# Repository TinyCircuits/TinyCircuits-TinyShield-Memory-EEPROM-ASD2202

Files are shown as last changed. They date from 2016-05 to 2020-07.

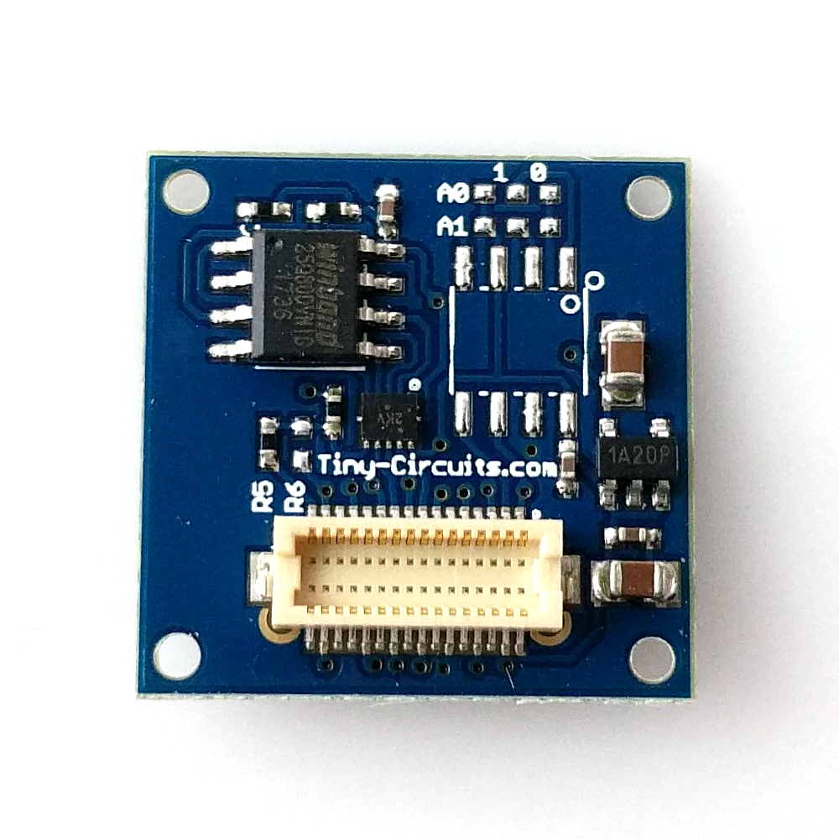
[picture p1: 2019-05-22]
images/Flash Memory/ASD2202-R-F-Tutorial-Image-01.jpg

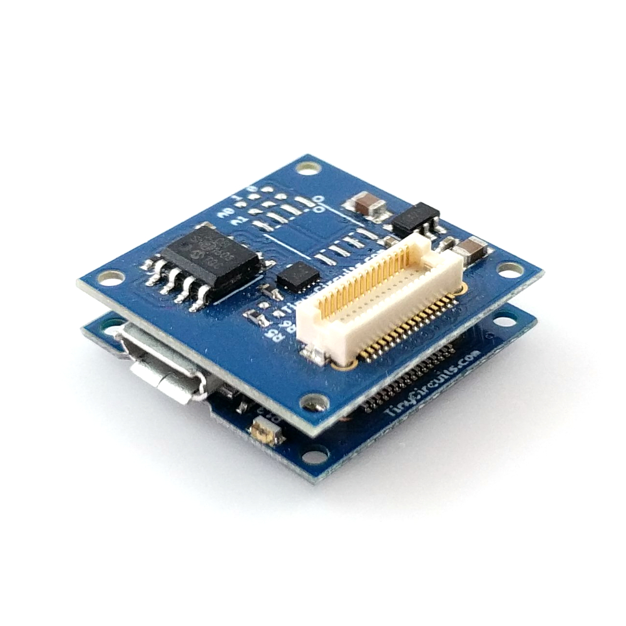
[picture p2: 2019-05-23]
images/SRAM/ASD2202-R-S-Tutorial-Image-03.jpg

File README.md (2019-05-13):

# TinyCircuits TinyShield EEPROM / Flash / SRAM Memory Board
## ASD2202 Rev3

The design files are located under design_files/ for the TinyCircuits ASD2202 Rev 3 PCB.  This is a TinyShield board (20mm x 20mm) that has options for several different memory ICs.

Format is in Cadsoft Eagle format - Eagle version 6.2 was used for the original design.

For more infomation on this, check out the product page at TinyCircuits.com:  https://tinycircuits.com/products/eeprom-tinyshield

# License:

Design by TinyCircuits.
All design files are released under the Creative Commons Attribution Share-Alike 3.0 License, see the following link for details: http://creativecommons.org/licenses/by-sa/3.0

All text above must be included in any redistribution or derived design

This project uses designs and concepts developed as part of the Arduino project and the LilyPad project.  The TinyCircuits design files themselves (schematics, PCB and libraries) are not directly derived from these works' design files and have been created new, however the concepts and basic architecture behind the TinyDuino and TinyLily products are derived and we thank the hard work of the organizations below for their contributions to open-source hardware:
  
Original Arduino Uno Design by Team Arduino

LilyPad Arduino Design by Leah Buechley and Sparkfun Electronics

Please support the open-source hardware community

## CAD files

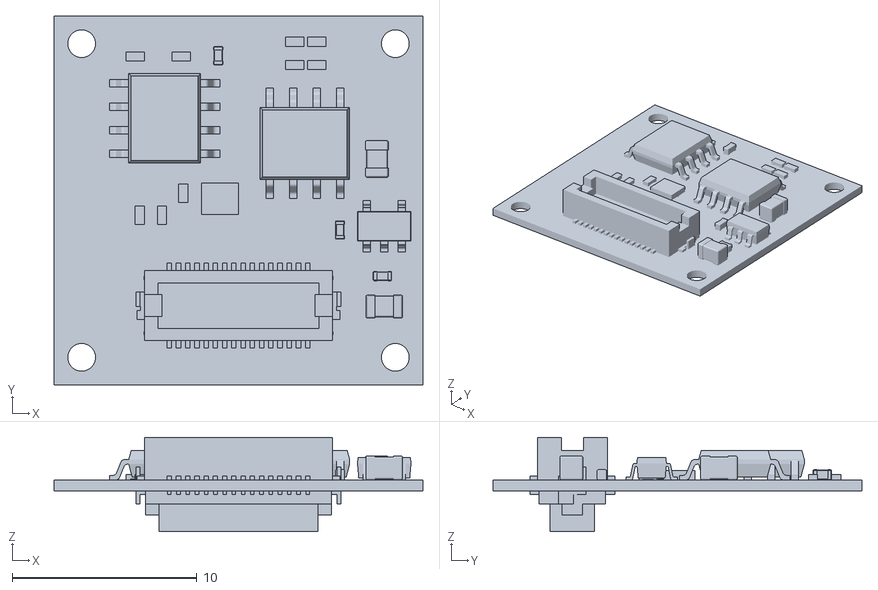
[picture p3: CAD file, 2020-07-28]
cad/TinyShield_EEPROM_ASD2202_REV3-STL.stl
20.0 x 20.0 x 5.10

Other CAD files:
cad/TinyShield_EEPROM_ASD2202_REV3-DETAILED_DRAWING-DXF.dxf

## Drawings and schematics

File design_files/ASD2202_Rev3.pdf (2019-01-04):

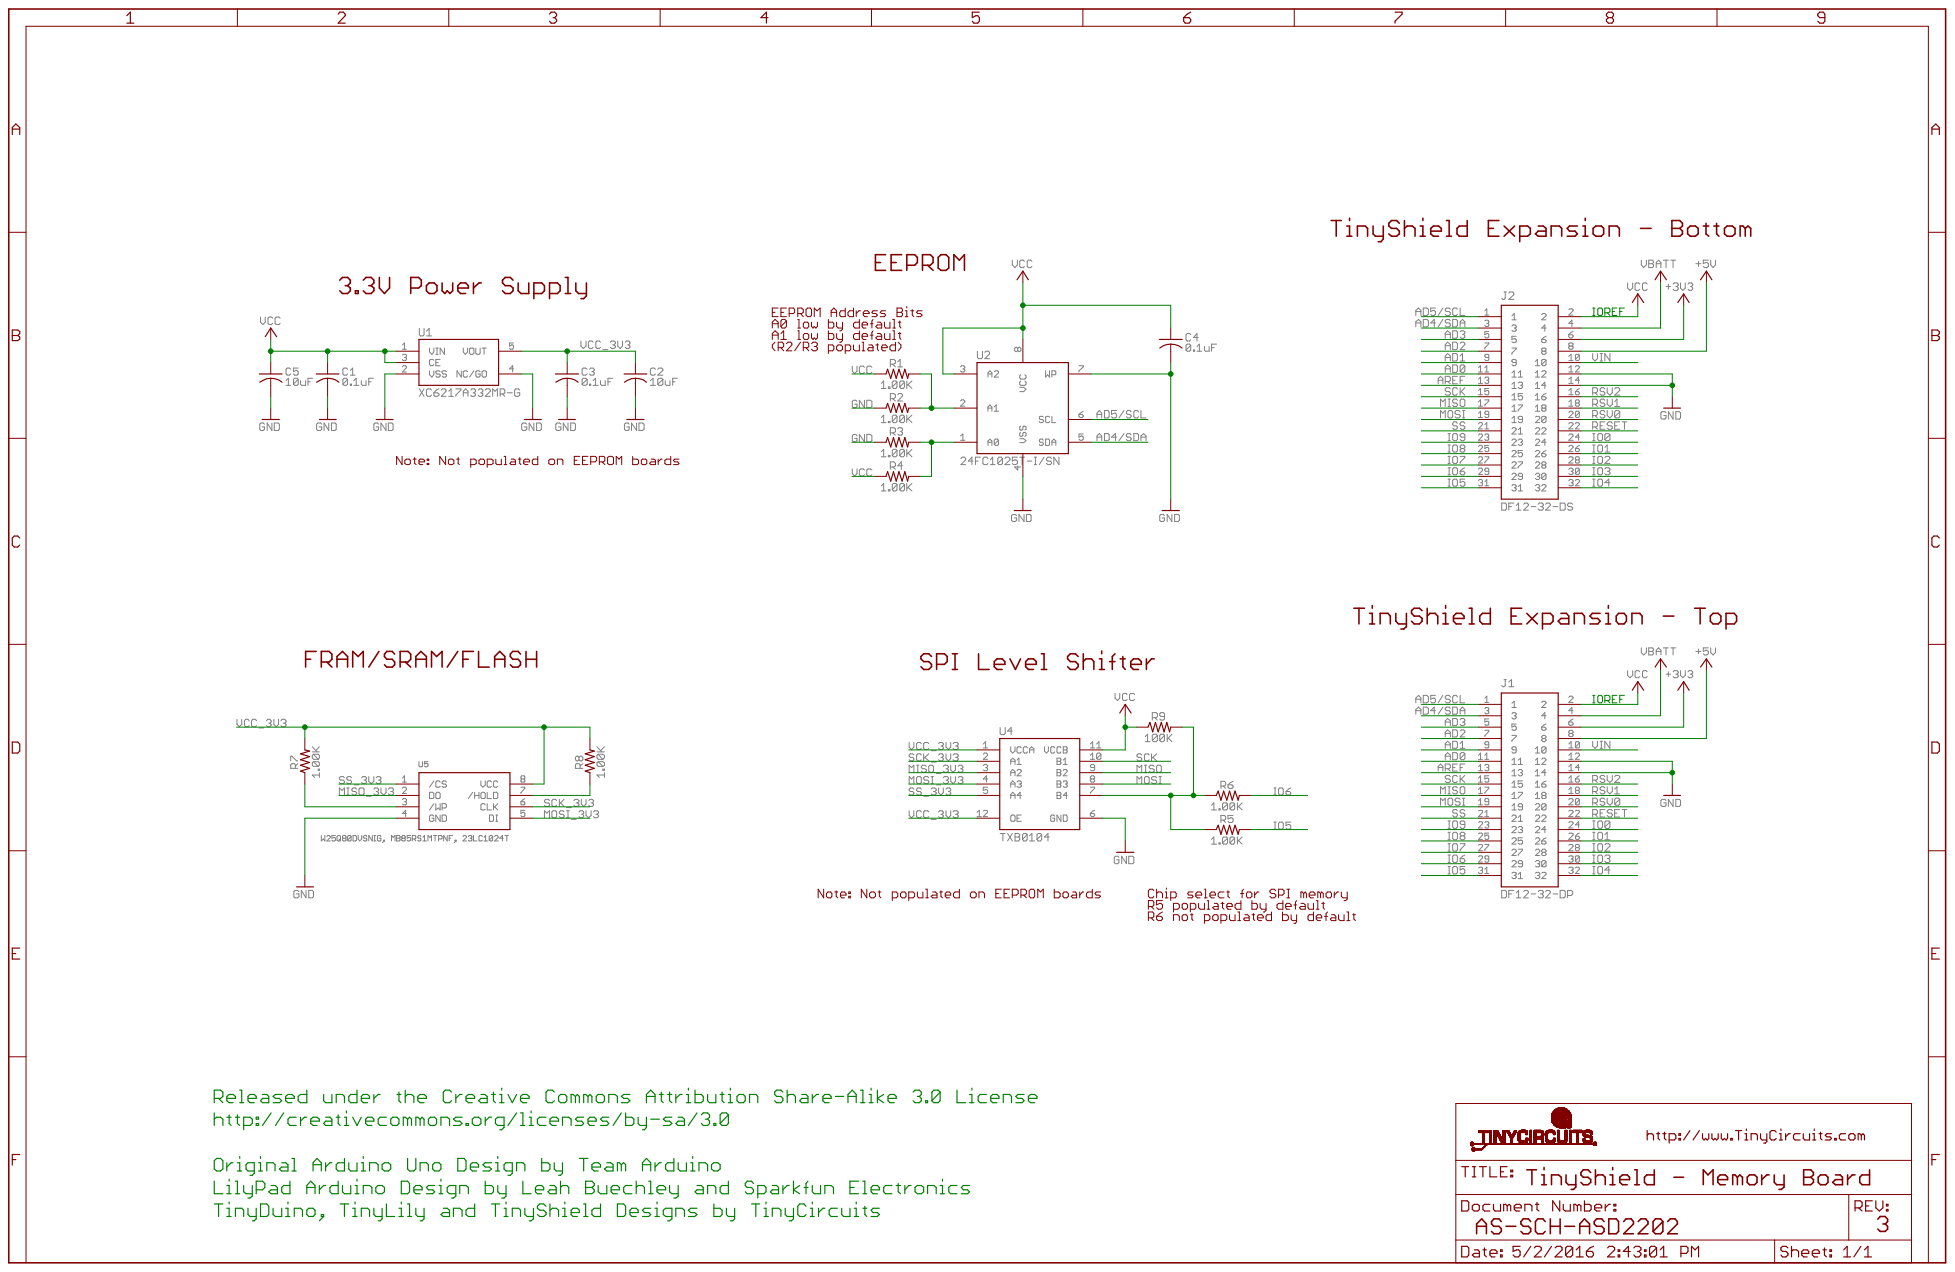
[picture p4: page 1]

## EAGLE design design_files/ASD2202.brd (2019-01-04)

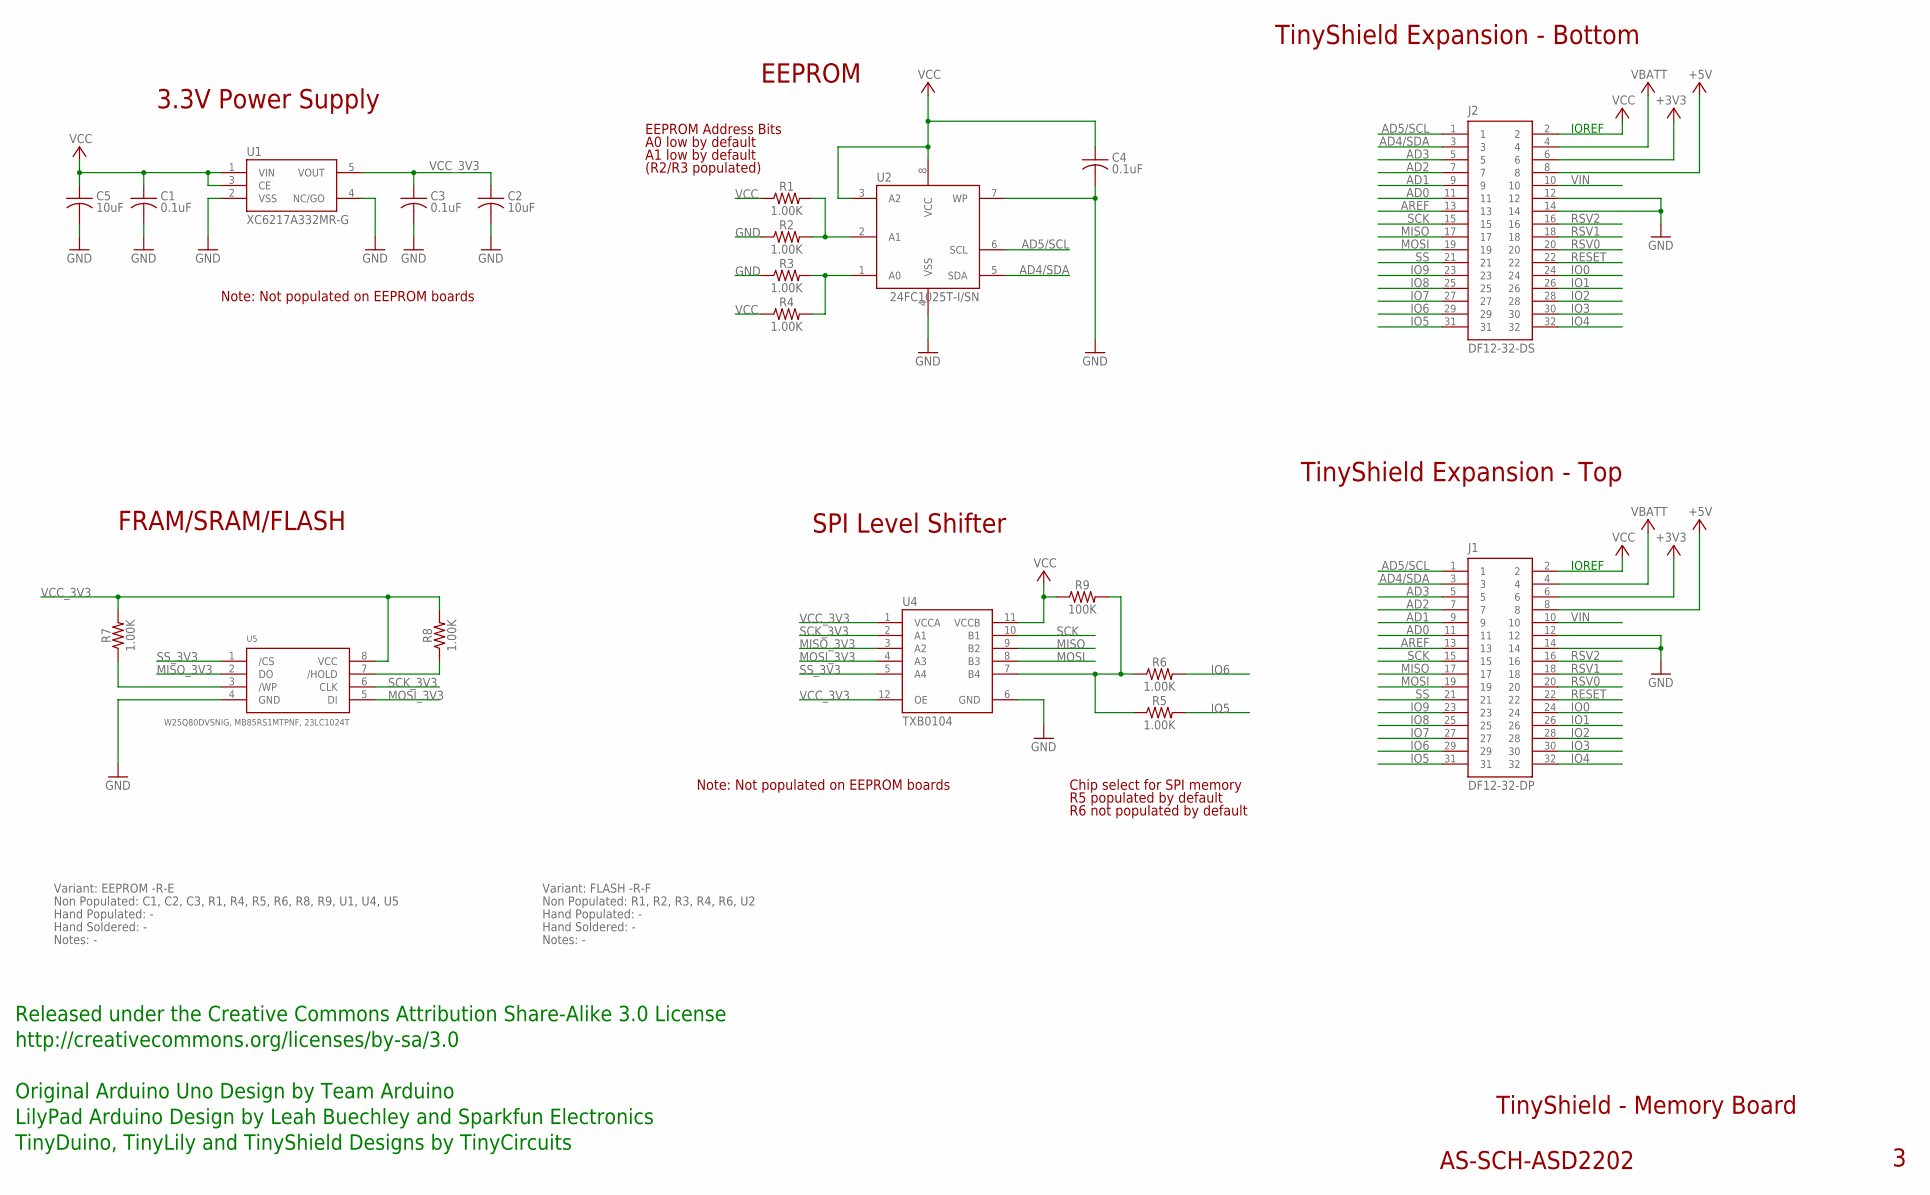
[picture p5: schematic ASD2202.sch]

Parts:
C1, C3, C4: 0.1uF; C0402; PARTNO AS-ITM-00008
C2: 10uF; C0805; PARTNO AS-ITM-00045
C5: 10uF; C0805
J1: DF12-32-DP; PARTNO AS-ITM-00015
J2: DF12-32-DS; PARTNO AS-ITM-00012
R1, R2, R3, R4, R5, R6: 1.00K; 0402; PARTNO AS-ITM-00003
R7, R8: 1.00K; 0402
R9: 100K; 0402; PARTNO AS-ITM-00004
U1: XC6217A332MR-G; SOT-25; PARTNO AS-ITM-00249
U2: 24FC1025T-I/SN; 8-SOIC-N
U4: TXB0104; UQFN-12
U5: W25Q80DVSNIG, MB85RS1MTPNF, 23LC1024T; 8-SOIC-N

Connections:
+3V3: J1.6, J2.6
+5V: J1.8, J2.8
AD0: J1.11, J2.11
AD1: J1.9, J2.9
AD2: J1.7, J2.7
AD3: J1.5, J2.5
AD4/SDA: J1.3, J2.3, U2.5 (SDA)
AD5/SCL: J1.1, J2.1, U2.6 (SCL)
AREF: J1.13, J2.13
GND: C1.2, C2.2, C3.2, C4.2, C5.2, J1.12, J1.14, J2.12, J2.14, R2.1, R3.1, U1.2 (VSS), U1.4 (NC/GO), U2.4 (VSS), U2.7 (WP), U4.6 (GND), U5.4 (GND)
IO0: J1.24, J2.24
IO1: J1.26, J2.26
IO2: J1.28, J2.28
IO3: J1.30, J2.30
IO4: J1.32, J2.32
IO5: J1.31, J2.31, R5.2
IO6: J1.29, J2.29, R6.2
IO7: J1.27, J2.27
IO8: J1.25, J2.25
IO9: J1.23, J2.23
MISO: J1.17, J2.17, U4.9 (B2)
MISO_3V3: U4.3 (A2), U5.2 (DO)
MOSI: J1.19, J2.19, U4.8 (B3)
MOSI_3V3: U4.4 (A3), U5.5 (DI)
unnamed: R8.1, U5.7 (/HOLD)
unnamed: R7.1, U5.3 (/WP)
unnamed: R1.2, R2.2, U2.2 (A1)
unnamed: R3.2, R4.2, U2.1 (A0)
unnamed: R5.1, R6.1, R9.2, U4.7 (B4)
RESET: J1.22, J2.22
RSV0: J1.20, J2.20
RSV1: J1.18, J2.18
RSV2: J1.16, J2.16
SCK: J1.15, J2.15, U4.10 (B1)
SCK_3V3: U4.2 (A1), U5.6 (CLK)
SS: J1.21, J2.21
SS_3V3: U4.5 (A4), U5.1 (/CS)
VBATT: J1.4, J2.4
VCC: C1.1, C4.1, C5.1, J1.2, J2.2, R1.1, R4.1, R9.1, U1.1 (VIN), U1.3 (CE), U2.3 (A2), U2.8 (VCC), U4.11 (VCCB)
VCC_3V3: C2.1, C3.1, R7.2, R8.2, U1.5 (VOUT), U4.1 (VCCA), U4.12 (OE), U5.8 (VCC)
VIN: J1.10, J2.10

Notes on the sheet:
TinyShield Expansion - Bottom
TinyShield - Memory Board
AS-SCH-ASD2202
TinyShield Expansion - Top
IOREF
Released under the Creative Commons Attribution Share-Alike 3.0 License
http://creativecommons.org/licenses/by-sa/3.0
LilyPad Arduino Design by Leah Buechley and Sparkfun Electronics
TinyDuino, TinyLily and TinyShield Designs by TinyCircuits
Original Arduino Uno Design by Team Arduino
EEPROM
3.3V Power Supply
SPI Level Shifter
FRAM/SRAM/FLASH
Chip select for SPI memory
R5 populated by default
R6 not populated by default
EEPROM Address Bits
A0 low by default
A1 low by default
(R2/R3 populated)
Note: Not populated on EEPROM boards
Non Populated: C1, C2, C3, R1, R4, R5, R6, R8, R9, U1, U4, U5
Hand Populated: -
Hand Soldered: -
Variant: EEPROM -R-E
Notes: -
Non Populated: R1, R2, R3, R4, R6, U2
Variant: FLASH -R-F

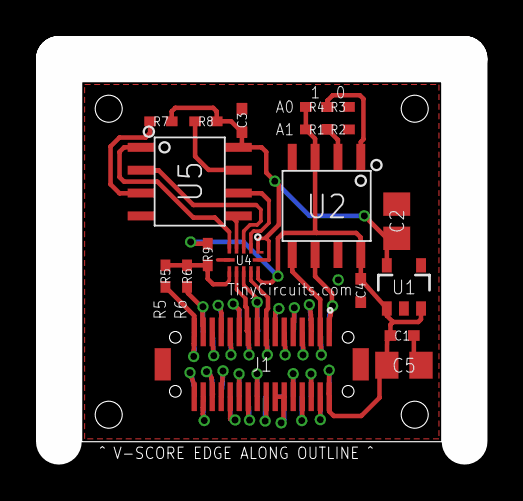
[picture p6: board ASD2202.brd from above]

Board: 2 copper layers, 20.0 x 20.0 mm, 21 parts (1 on the bottom side), 41 nets.

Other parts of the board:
U$1: DOCFIELD-TINYCIRCUITS-PCB

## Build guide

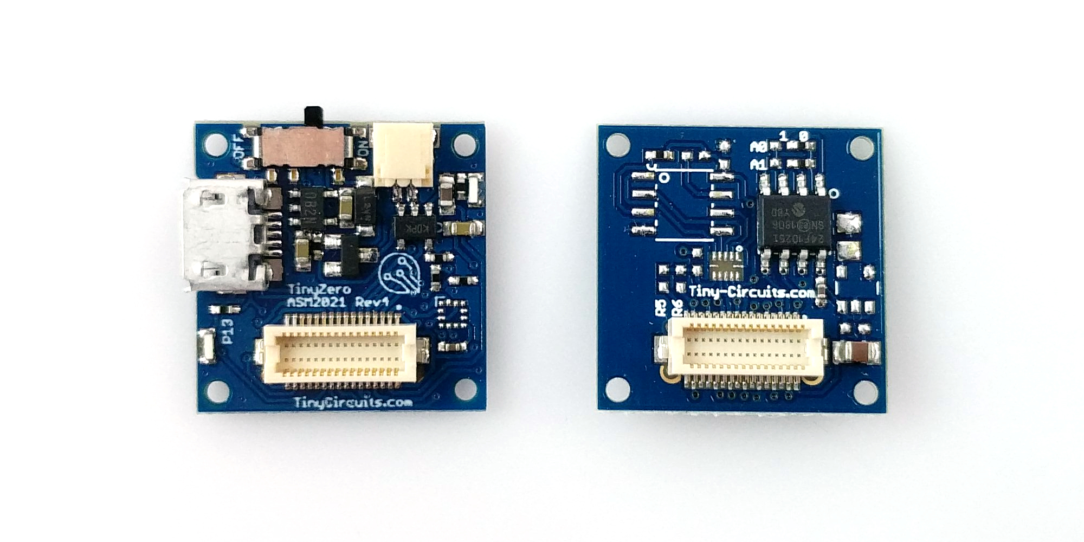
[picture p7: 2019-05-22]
images/EEPROM/ASD2202-R-E-Tutorial-Image-02.jpg

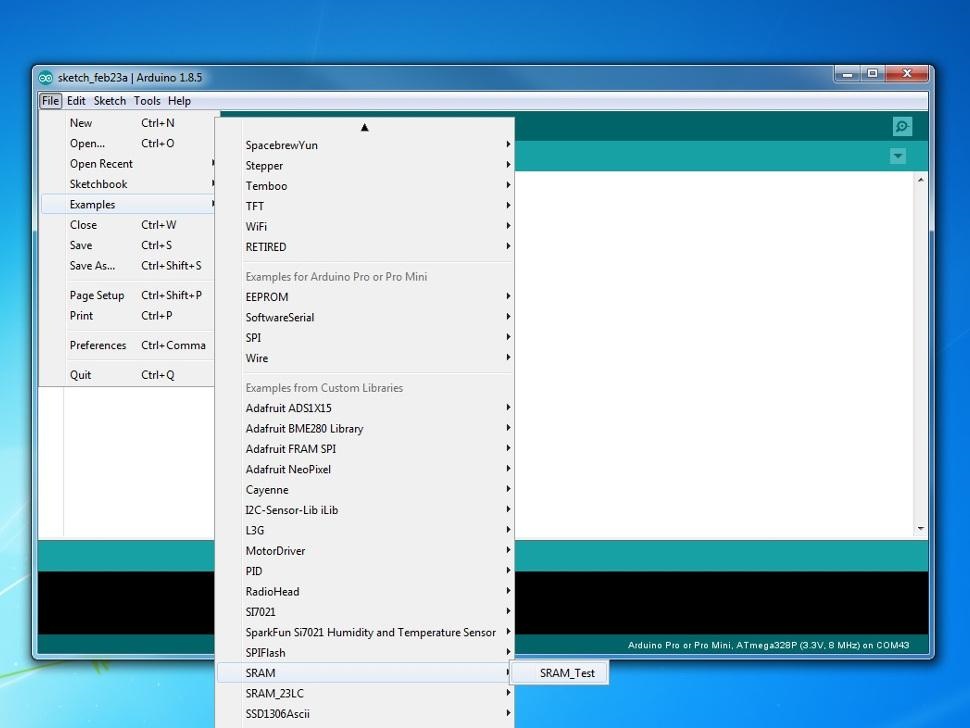
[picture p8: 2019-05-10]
images/SRAM/ASD2202-R-S-Tutorial-Image-05.png

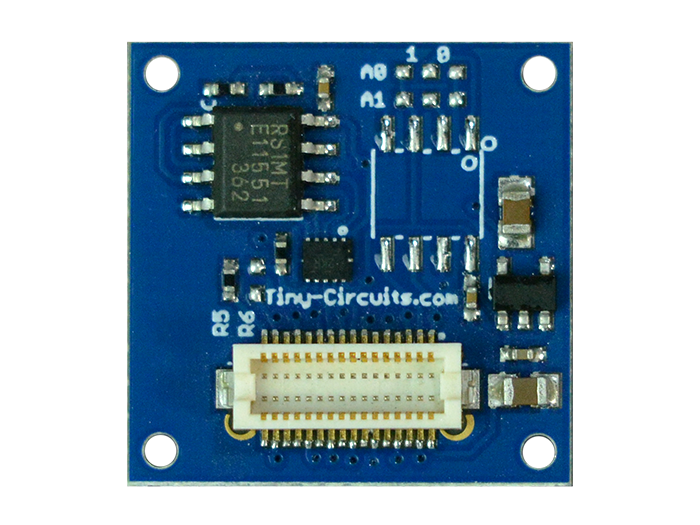
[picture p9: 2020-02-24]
images/FRAM/ASD2202-R-M-Tutorial-Image-01.png

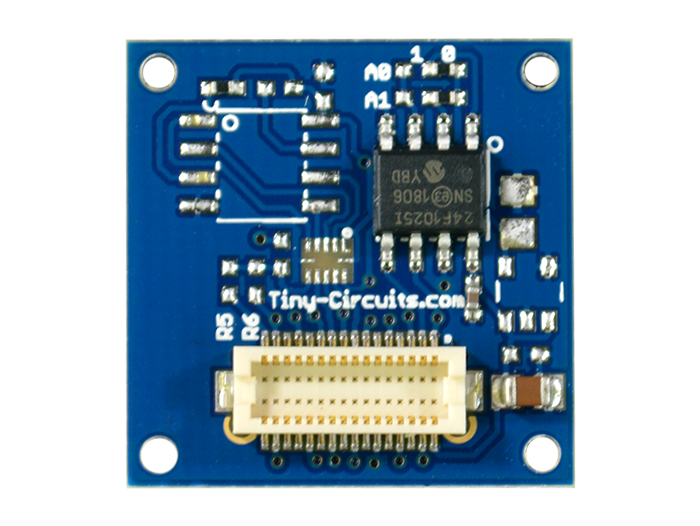
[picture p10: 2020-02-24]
images/EEPROM/ASD2202-R-E-Tutorial-Image-01.png

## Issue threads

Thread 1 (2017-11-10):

Header typo?

dunk8888, 2017-11-10:
Hi,is this for the spi flash or i2c as its says i2c in the header,ime sure its spi.cheers

TinyCircuits, 2020-01-10:
You're correct! Thank you!

Closed 2020-01-10.

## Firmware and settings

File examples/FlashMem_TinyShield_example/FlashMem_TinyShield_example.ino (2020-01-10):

/*
  TinyCircuits Flash Memory TinyShield Example Sketch
  
  This is an example of how to write to and read data from the Winbond W25Q80DV
  Flash Memory chip using the SPIFlash library. Whole page write functions are
  not used. This example will specifically be using the writeByte/readByte
  functions. Documentation on functions for other data types can be found on
  the library's Github page.

  SPIFlash is authored by Marzogh: https://github.com/Marzogh/SPIFlash

  Written 19 January 2017
  By Lilith Freed
  Modified 07 January 2019
  By Hunter Hykes

  https://TinyCircuits.com
*/

#include <SPIFlash.h>

// Decide what Serial port to use!
#ifdef ARDUINO_ARCH_SAMD
  #define SerialMonitor SerialUSB // Our TinyScreen+ is an SAMD board.
#else
  #define SerialMonitor Serial
#endif

const int flashCS = 5; // The chip/slave select pin is pin 5.

SPIFlash flash(flashCS); // The SPIFlash object for the chip. Passed the chip select pin in the constructor.
uint16_t page; // The page to be written to. (Page value MUST be type uint16_t)
uint8_t offset; // The specific location on the page. (Offset value MUST be type uint8_t)
uint32_t address; // The specific address in memory to be written to. (Address value MUST be type uint32_t)
const bool errorCheck = true; // A boolean parameter used to check for writing errors. Turned on by default.
const bool fastRead = false; // A boolean parameter used to implement a fast read function. Defaults to false.

void setup() {
  SerialMonitor.begin(115200);
  while(!SerialMonitor); // This will ensure the serial monitor is OPEN before writing to it on TinyScreen+.
  
  SerialMonitor.println("Initializing Flash Memory...");
  SerialMonitor.println();
  pinMode(flashCS, OUTPUT); // Ensure chip select pin is an output. This line is currently REQUIRED for proper operation.
  flash.begin(); // Boots the flash memory
  SerialMonitor.println(); 

  page = random(0, 4095); // The W25Q80DV has 4,096 writeable pages, referenced as 0-4095 in this library.
  offset = random(0, 255); // There are 256 individually addressable bytes per page, referenced 0-255.
  address = (page * 255) - (255 - offset); // Calculates the proper address given the page and offset.
  /* Writing/Reading a byte */
  SerialMonitor.println("Using writeByte...");
  uint8_t testByte = 8; // Byte data to be written to flash memory
  flash.eraseSector(address); // Must erase memory before writing per datasheet.
  // writeByte(address, testByte, errorCheck) - returns true if successful
  // address: int 0-(4095*255)
  // testByte: uint8_t or byte type data
  // errorCheck: bool
  if(flash.writeByte(address, testByte, errorCheck)) { 
    SerialMonitor.println("Write successful!");
  }
  else {
    SerialMonitor.println("Write failed!");
  }
  SerialMonitor.println("Using readByte...");
  char printBuffer[50]; // for formatting the random values, using sprintf
  sprintf(printBuffer, "The byte on page %d at position %d is: ", page, offset);
  SerialMonitor.print(printBuffer);
  // readByte(address, fastRead)
  SerialMonitor.println(flash.readByte(address, fastRead)); // This should read 8 on the serial monitor.

}

void loop() {
  // Code that runs repeatedly goes here.
}

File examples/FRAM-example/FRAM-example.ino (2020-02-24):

/**********************************************************************
 * FRAM Memory TinyShield Example:
 * Performs a basic write and read operation of a string to FRAM chip
 * 
 * Written by: Laveréna Wienclaw for TinyCircuits
 * Initialized: Feb 2020
 * Last modified: 
 *********************************************************************/

#include <FRAM.h>

// Make Serial Monitor compatible for all TinyCircuits processors
#if defined(ARDUINO_ARCH_AVR)
  #define SerialMonitorInterface Serial
#elif defined(ARDUINO_ARCH_SAMD)
  #define SerialMonitorInterface SerialUSB
#endif

uint8_t FRAM_CS_PIN = 5;
FRAM fram(FRAM_CS_PIN);

void setup() {
  SerialMonitorInterface.begin(9600);
  fram.begin();
}

void loop() {
  char test [] = "hello, world";
  fram.seek(1);
  SerialMonitorInterface.print("Data to write: ");
  SerialMonitorInterface.println(test);
  fram.write((byte *) test, sizeof test);
  char buf[100];
  fram.seek(1);
  fram.readBytes((char *) buf, sizeof buf);
  SerialMonitorInterface.print("Data read: ");
  SerialMonitorInterface.println(buf);
  delay(1000);

//  int framData = fram.read();
//  SerialMonitorInterface.println(framData);
}

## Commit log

2019-01-04 update format
    [ASD2202.brd, ASD2202.sch]
2019-05-24 fix el eeprom:
2020-07-28 Add CAD data
    [TinyShield_EEPROM_ASD2202_REV3-DETAILED_DRAWING-DXF.dxf, TinyShield_EEPROM_ASD2202_REV3-STL.stl]
2020-08-14 Update CAD drawing
    [TinyShield_EEPROM_ASD2202_REV3-DETAILED_DRAWING-DXF.dxf]
